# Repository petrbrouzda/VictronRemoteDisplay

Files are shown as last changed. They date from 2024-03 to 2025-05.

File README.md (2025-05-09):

# VictronRemoteDisplay
Simple remote (wifi connected) status display for Victron photovoltaic system with Cerbo GX central system without cloud access - for environments without internet connection.

Victron photovoltaic systems with Cerbo GX has display module (GX Touch 50, GX Touch 70) but they are connected to Cerbo by cable. And they are touch-enabled - you can change view, you can change system settings. 

I need wifi-connected display with **only** passive function (no configuration changes), and it run in no-internet environment (no connection to Victron VRM cloud).

So I've build this 3.5" display - as described in [VictronDisplay35](VictronDisplay35/README.md)  directory:
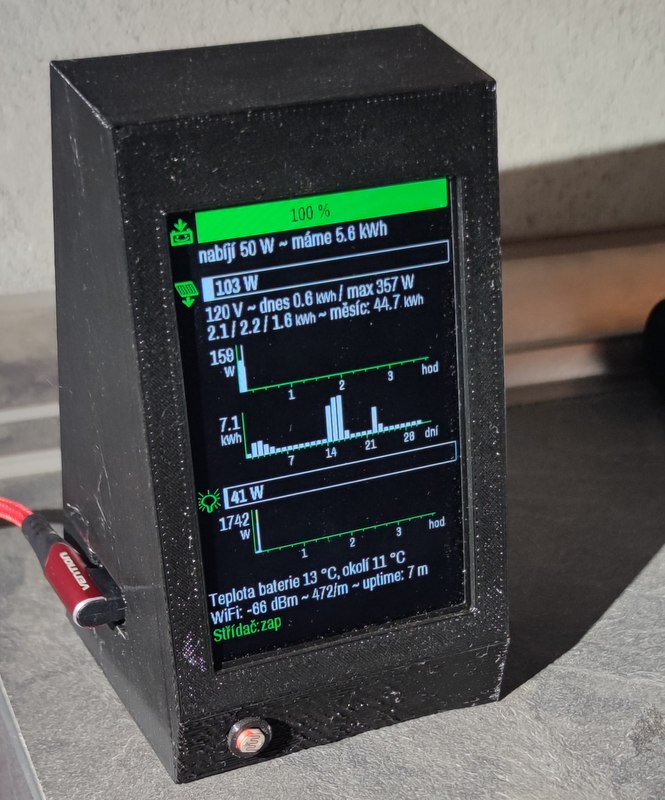
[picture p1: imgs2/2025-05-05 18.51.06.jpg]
 

Previous 1.8" display version is documented in [VictronDisplay18](VictronDisplay18/README.md)  directory:
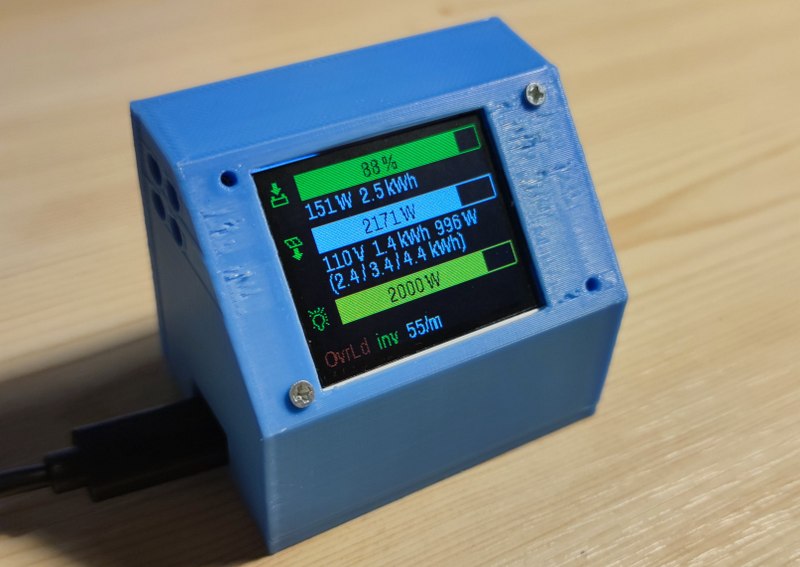
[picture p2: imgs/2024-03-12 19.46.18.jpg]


## How it works

Cerbo GX offers WiFi access point. And Cerbo GX has MQTT broker built in - you just have to switch it on in Settings. 

ESP32 can connect to Cerbo's WiFi, then connect to MQTT broker and get all information about your photovoltaic system. Seems easy.

But when you connect to Cerbo's MQTT and subscribe to all topics ("#"), you've got only one topic with ID of Cerbo's system:

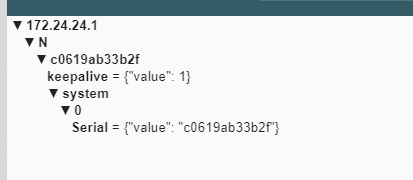
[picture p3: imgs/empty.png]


You have to read the system ID and publish **keeepalive message**: empty message to topic `R/<system ID>/keepalive` - for example `R/c0619ab33b2f/keepalive`

After you send the message, MQTT will magically starts filling with data:
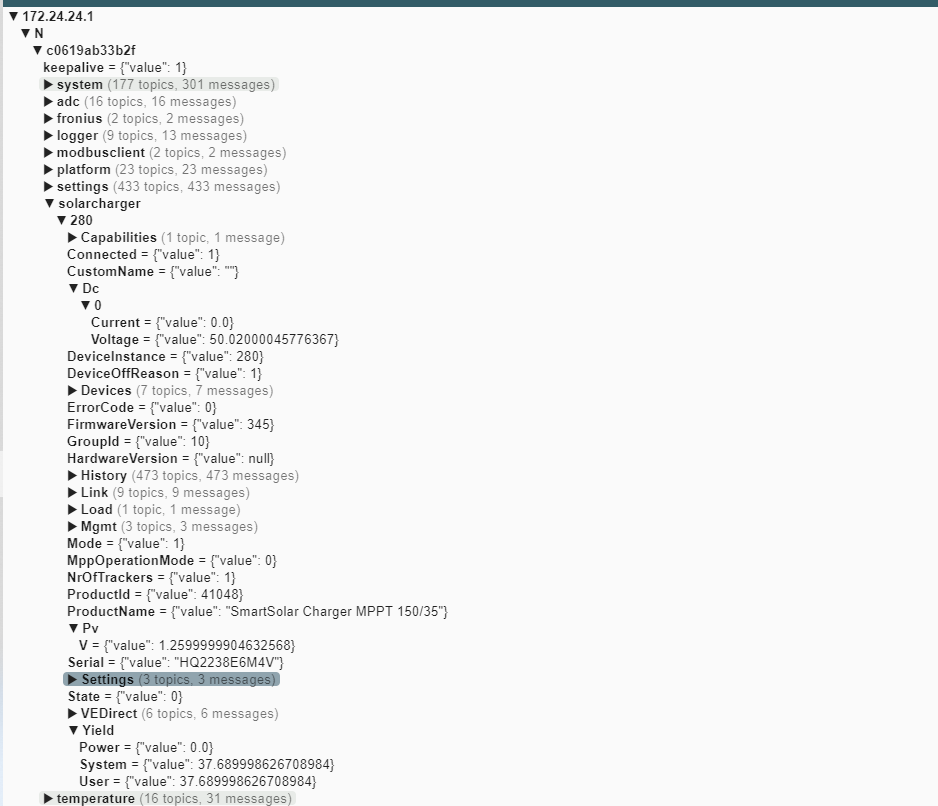
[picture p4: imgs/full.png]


But your happiness will last only for one minute, then Cerbo stops publishing more data until you send another keepalive message. So you have to send keepalive message periodically, every 55 seconds.

## Limitations

Application has been tested on three photovoltaic systems only.

It is not generic / universal tool - for example it reads data only for one battery module. If you have more batteries and they are reported as separate modules, you will have to change application. We're using two Pylontech batteries connected by data link - and they are reported as one module in Victron.

I'm using it on off-grid system, so it doesn't look for grid consumption/production. 

## Resources

https://community.victronenergy.com/questions/155407/mqtt-local-via-mqtt-broker.html

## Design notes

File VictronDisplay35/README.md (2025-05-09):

# VictronRemoteDisplay
Simple remote (wifi connected) status display for Victron photovoltaic system (with Cerbo GX central system) without cloud access - for environments without internet.

Victron photovoltaic systems with Cerbo GX has display module (GX Touch 50, GX Touch 70) but they are connected to Cerbo by cable. And they are touch-enabled - you can change view, you can change system settings. 

I need wifi-connected display with **only** passive function (no configuration changes), and it run in no-internet environment (no connection to Victron VRM cloud).

So I've build this:

 

It runs basic [ESP32-C3 board](https://s.click.aliexpress.com/e/_DEw2w8v) with [cheap 3.5" SPI display](https://s.click.aliexpress.com/e/_opxDnTV). 

Connection (display pin - ESP32 pin) is defined in config.h:
- CS - GPIO 7
- RST - GPIO 10
- DC - GPIO 6 
- SDA - GPIO 3
- SCL - GPIO 2
- BKL - GPIO 5
- VCC - 3V3
- GND - GND

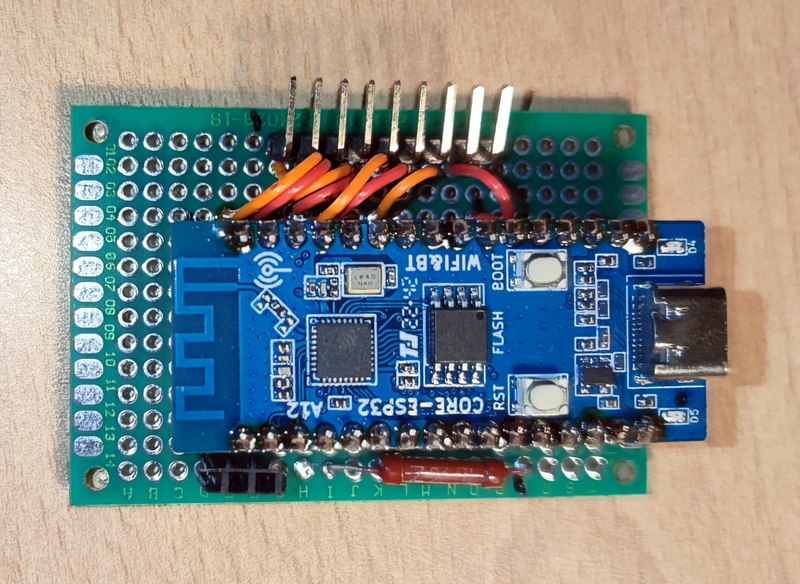
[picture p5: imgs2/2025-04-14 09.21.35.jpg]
 

There is also photoresistor for automatic backlight intensity setting. 
It is connected to GPIO 0 and used in voltage divider - so when there is much light around, voltage on GPIO 0 drops to zero; in darkness, voltage is >2.5 V.

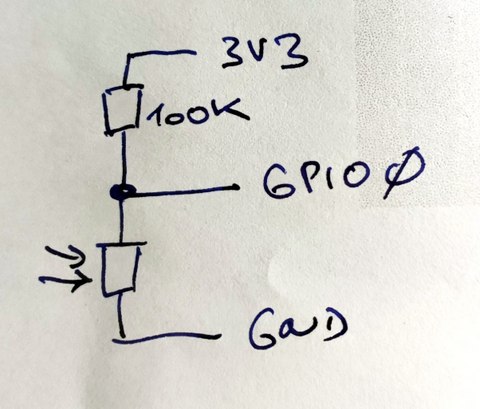
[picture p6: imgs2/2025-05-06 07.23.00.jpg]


If you haven't photoresistor, you can disable the functionality by commenting out this line in config.h:

``#define USE_BRIGHTNESS_SENSOR 
``

Box is 3D printed, STL files are in [box-display35](/box-display35/) folder.

## How it works

Cerbo GX offers WiFi access point. And Cerbo GX has MQTT broker built in - you just have to switch it on in Settings. 

ESP32 can connect to Cerbo's WiFi, then connect to MQTT broker and get all information about your photovoltaic system. Seems easy.

But when you connect to Cerbo's MQTT and subscribe to all topics ("#"), you've got only one topic with ID of Cerbo's system:



You have to read the system ID and publish **keeepalive message**: empty message to topic `R/<system ID>/keepalive` - for example `R/c0619ab33b2f/keepalive`

After you send the message, MQTT will magically starts filling with data:


But your happiness will last only for one minute, then Cerbo stops publishing more data until you send another keepalive message. So you have to send keepalive message periodically, every 55 seconds.

## How to run it

This is tested on ESP32 core for arduino version **2.0.17** (version in "board manager" in Arduino IDE). It **will not** run on current 3.0.x versions as some APIs changed in them. Switch board version to 2.0.17 before building it!

1) If your Cerbo is not connected to WiFi: switch on WiFi access point in Cerbo GX.

2) In Cerbo's console, go to **Settings - Services** and switch on **MQTT on Lan (SSL)**. Then another option will appear: **MQTT on Lan (plaintext)**. Switch it on also.

3) Edit **config.h** section with your photovoltaic system limits:

```
#define SOLAR_PANELS_POWER_WP (6.0*450.0)
#define INVERTER_POWER_W 2400.0
#define BATTERY_CAPACITY_KWH 7.0
```

4) Edit **config.h** section with connection parameters. MQTT broker address is address of Cerbo GX.

```
// WiFi
#define WIFI_SSID (const char *)"venus-XXXXXXXX-xxx"
#define WIFI_PASSWORD (const char *)"xxxxxxxx"

// MQTT Broker
#define MQTT_BROKER (const char *)"172.24.24.1"
```

5) Board configuration:
- if you have board with serial-to-USB converter: `USB-CDC on boot: disabled`
- if you have board with no serial-to-USB converter, with direct USB to ESP32-C3: `USB-CDC on boot: enabled`
- `Flash mode: DIO`
- `CPU speed: 80 MHz`
- `Flash speed: 40 MHz`

6) Used libraries (should be installed in library manager):
* PubSubClient 2.8 
* Tasker 2.0.3
* ArduinoJson 6.21.5 
* Adafruit ST7735 and ST7789 Library 1.11.0
* Adafruit GFX Library 1.12.0
* Adafruit BusIO  1.17.0
* ESP32AnalogRead 0.3.0 

7) Build application, send it into ESP and enjoy.

## What is displayed?

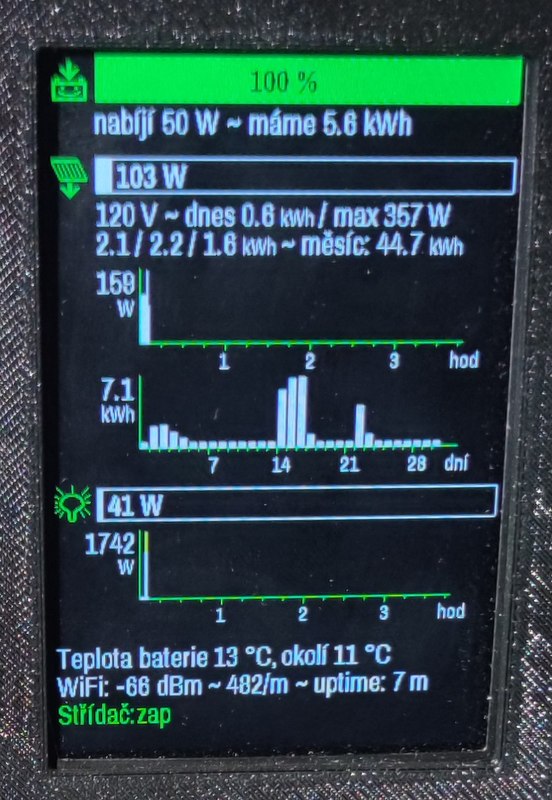
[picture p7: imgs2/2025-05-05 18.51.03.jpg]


**First bar** is **battery status.** 
* Battery icon shows if battery is charged or discharged. 
* Percentage is shown as "usable capacity". Battery will cut off at 20 %, so you've got technical reading 20 % - 100 %, which will be displayed as 0 % - 100 % here. 
* First data item (50 W) is power consumed (negative) or charging (positive). 
* Then estimated energy available (5.6 kWh); and when battery is discharged, estimated time battery will be able to suply current consumption.

Variants:

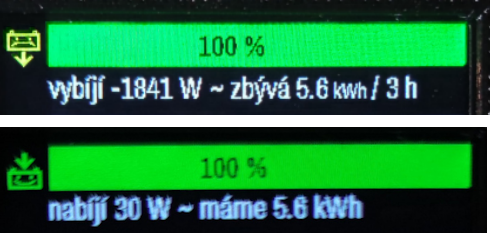
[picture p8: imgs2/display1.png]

* battery is discharging at 1841 W, estimated energy available is 5.6 kWh and it will remain for 3 hours
* battery is charging by 30 W, 5.6 kWh is available

**Second bar** is status of **solar panels**. 103 W in bar is current power supplied by panels. 
* First data row contains: 120 V = panels voltage; 0.6 kWh = today's yield; max 357 W = today maximum power supplied
* Second data row: yield yesterday / two days back / three days back; summary yield during last 31 days

Then two charts are displayed:
* panels power (W) in every minute for the last 3.5 hour
* daily yield (kWh) for last 31 days

**Third bar** is **consumption**. 41 W consumed at the moment.

It is followed by chart of consumed power in every minute for the last 3.5 hours - so you can see that the maximal consumption was 1742 W.

At the bottom three rows of status data are displayed:
* Temperature of batteries and inverter.
* WiFi strength; number of messages processed in last minute (as debug information - if connection is somewhat broken, there will be 0/m); display uptime
* Status LEDs of inverter.

## Application limitations

Application has been tested on three photovoltaic systems only.

It is not generic / universal tool - for example it reads data only for one battery module. If you have more batteries and they are reported as separate modules, you will have to change application. We're using two Pylontech batteries connected by data link - and they are reported as one module in Victron.

I'm using it on off-grid system, so it doesn't look for grid consumption/production.  

## Resources

https://community.victronenergy.com/questions/155407/mqtt-local-via-mqtt-broker.html

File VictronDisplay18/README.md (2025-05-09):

# VictronRemoteDisplay

**This is old, obsoleted version. Better version with bigger display and more information displayed is in [VictronDisplay35](../VictronDisplay35/README.md)  directory.**

Simple remote (wifi connected) status display for Victron photovoltaic system (with Cerbo GX central system) without cloud access - for environments without internet.

Victron photovoltaic systems with Cerbo GX has display module (GX Touch 50, GX Touch 70) but they are connected to Cerbo by cable. And they are touch-enabled - you can change view, you can change system settings. 

I need wifi-connected display with **only** passive function (no configuration changes), and it run in no-internet environment (no connection to Victron VRM cloud).

So I've build this:



It runs basic [ESP32-C3 board](https://s.click.aliexpress.com/e/_DEw2w8v) with [cheap 1.8" SPI display](https://s.click.aliexpress.com/e/_DeaLqWd). Without soldering - by using dupont F-F cables:
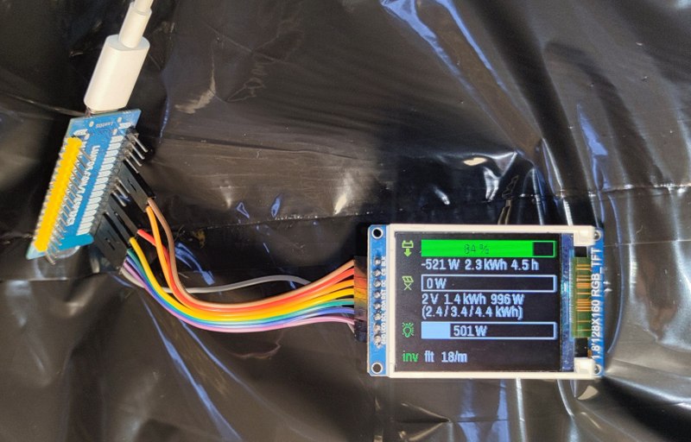
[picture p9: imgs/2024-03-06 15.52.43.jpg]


Connection (display pin - ESP32 pin):
- CS - GPIO 7
- RST - GPIO 6
- DC - GPIO 5 
- SDA - GPIO 3
- SCL - GPIO 2
- BKL - GPIO 4
- VCC - 3V3
- GND - GND

Box is 3D printed, STL files are in [box-display18](box-display18/) folder.

## How it works

Cerbo GX offers WiFi access point. And Cerbo GX has MQTT broker built in - you just have to switch it on in Settings. 

ESP32 can connect to Cerbo's WiFi, then connect to MQTT broker and get all information about your photovoltaic system. Seems easy.

But when you connect to Cerbo's MQTT and subscribe to all topics ("#"), you've got only one topic with ID of Cerbo's system:



You have to read the system ID and publish **keeepalive message**: empty message to topic `R/<system ID>/keepalive` - for example `R/c0619ab33b2f/keepalive`

After you send the message, MQTT will magically starts filling with data:


But your happiness will last only for one minute, then Cerbo stops publishing more data until you send another keepalive message. So you have to send keepalive message periodically, every 55 seconds.

## How to run it

This is tested on **2.0.x** version of ESP32 core for arduino (version in "board manager" in Arduino IDE). Probably will not run on current 3.0.x versions. Switch board version to 2.0.17 before building it!

1) If your Cerbo is not connected to WiFi: switch on WiFi access point in Cerbo GX.

2) In Cerbo's console, go to **Settings - Services** and switch on **MQTT on Lan (SSL)**. Then another option will appear: **MQTT on Lan (plaintext)**. Switch it on also.

3) Edit **config.h** section with your photovoltaic system limits:

```
#define SOLAR_PANELS_POWER_WP (6.0*450.0)
#define INVERTER_POWER_W 2400.0
#define BATTERY_CAPACITY_KWH 3.5
#define INVERTER_OWN_CONSUMPTION 20.0
```

4) Edit **config.h** section with connection parameters. MQTT broker address is address of Cerbo GX.

```
// WiFi
#define WIFI_SSID (const char *)"venus-XXXXXXXX-xxx"
#define WIFI_PASSWORD (const char *)"xxxxxxxx"

// MQTT Broker
#define MQTT_BROKER (const char *)"172.24.24.1"
```

5) Board configuration:
- if you have board with serial-to-USB converter: `USB-CDC on boot: disabled`
- if you have board with no serial-to-USB converter, with direct USB to ESP32-C3: `USB-CDC on boot: enabled`
- `Flash mode: DIO`
- `CPU speed: 80 MHz`
- `Flash speed: 40 MHz`

6) Used libraries:
* PubSubClient 2.8 
* Tasker 2.0.3
* ArduinoJson 6.21.4 
* Adafruit ST7735 and ST7789 Library 1.10.0
* Adafruit GFX Library 1.11.8
* Adafruit BusIO  1.14.4 

7) Build application, send it into ESP and enjoy.

## What is displayed?

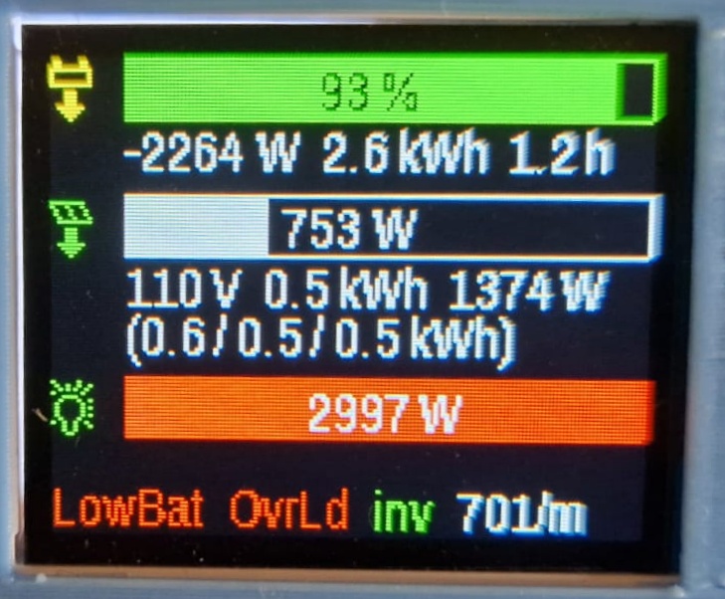
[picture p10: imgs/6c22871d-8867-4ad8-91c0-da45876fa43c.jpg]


**First bar** is **battery status.** 
* Battery icon shows if battery is charged or discharged. 
* Percentage is shown as "usable capacity". Battery will cut off at 20 %, so you've got technical reading 20 % - 100 %, which will be displayed as 0 % - 100 % here.
* First data item (-2264 W) is power consumed (negative) or charging (positive). 
* Then estimated energy available (2.6 kWh) and estimated time battery will be able to suply current consumption.

**Second bar** is status of **solar panels**. 753 W in bar is current power supplied by panels. 
* First data row contains: 110 V = panels voltage; 0.5 kWh = today's yield; 1374 W = today maximum power supplied
* Second data row: yield yesterday / two days back / three days back

**Third bar** is **consumption**. 2997 W consumed at the moment.

Last line are LEDs on inverter, so:
* Low Battery (correct - there is only one battery, which is unsupported configuration for 3 KW consumption)
* Overload (correct, inverter is rated for constant output of 2400 W)
* inv = "Inverter on"
* Last field is number of messages processed per minute (as debug information - if connection is somewhat broken, there will be 0/m).

## Application limitations

Application has been tested on only one photovoltaic system - mine. 

It is not generic / universal tool - for example it reads data only for one battery module. If you have more batteries, you will have to change application.

I'm using it on off-grid system, so it doesn't look for grid consumption/production. 

## Resources

https://community.victronenergy.com/questions/155407/mqtt-local-via-mqtt-broker.html

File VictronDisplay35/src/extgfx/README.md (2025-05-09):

Graphics objects for Adafruit_GFX and Arduino_GFX displays.

Homepage: https://github.com/petrbrouzda/ExtGfx

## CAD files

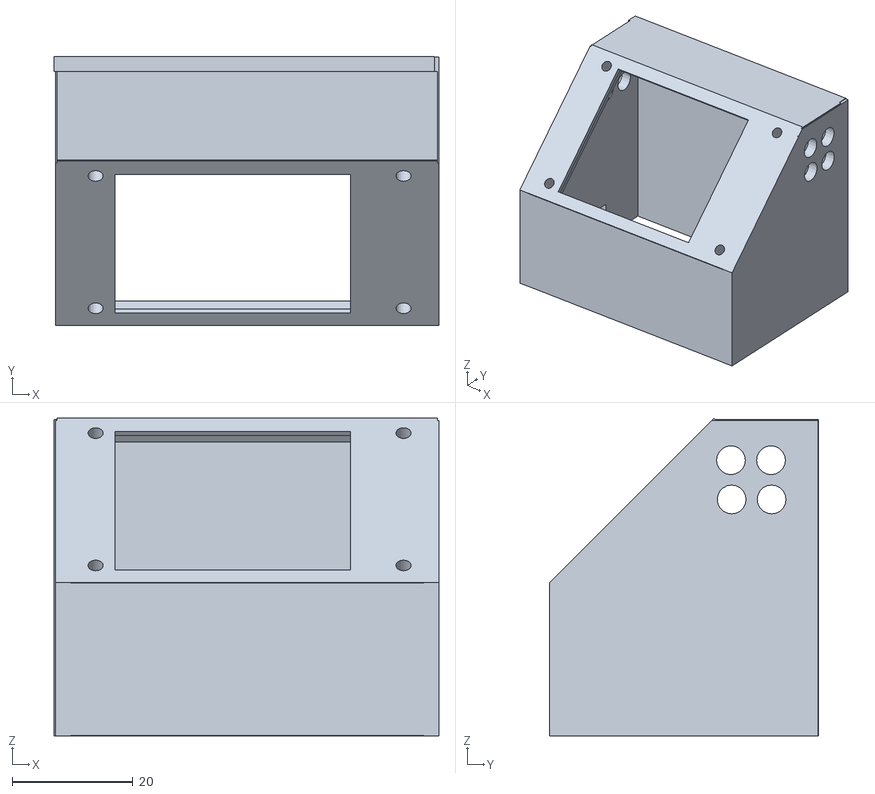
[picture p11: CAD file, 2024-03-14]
box-display18/top.stl
63.8 x 44.6 x 52.6

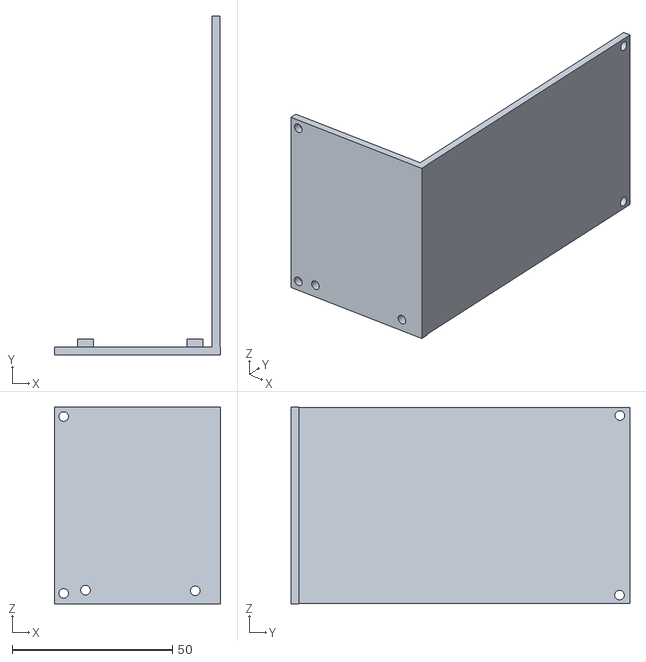
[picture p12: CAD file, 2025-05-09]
box-display35/back.stl
51.9 x 105.9 x 61.4

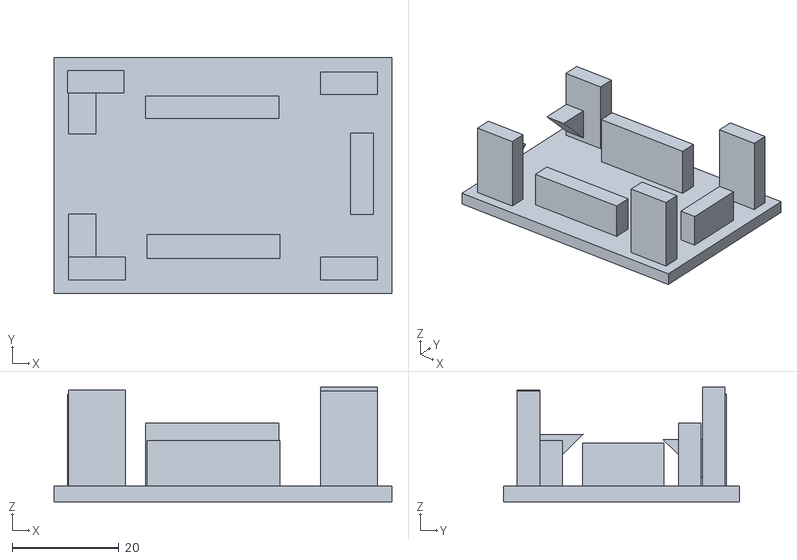
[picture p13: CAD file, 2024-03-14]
box-display18/bottom.stl
63.4 x 44.3 x 21.5

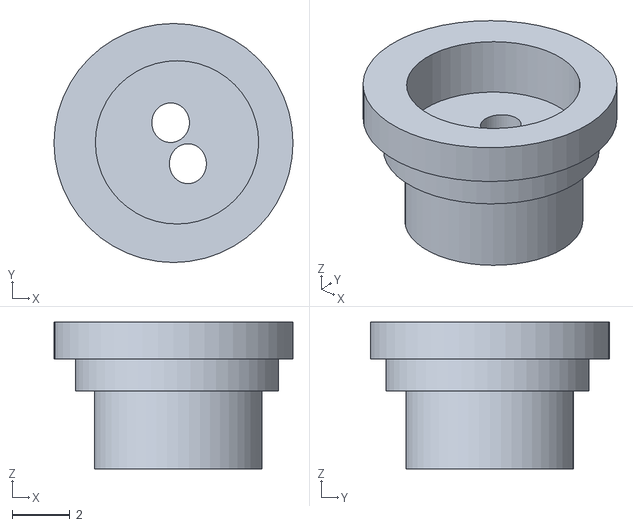
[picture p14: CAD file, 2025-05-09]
box-display35/photoresistor holder.stl
8.30 x 8.30 x 5.10

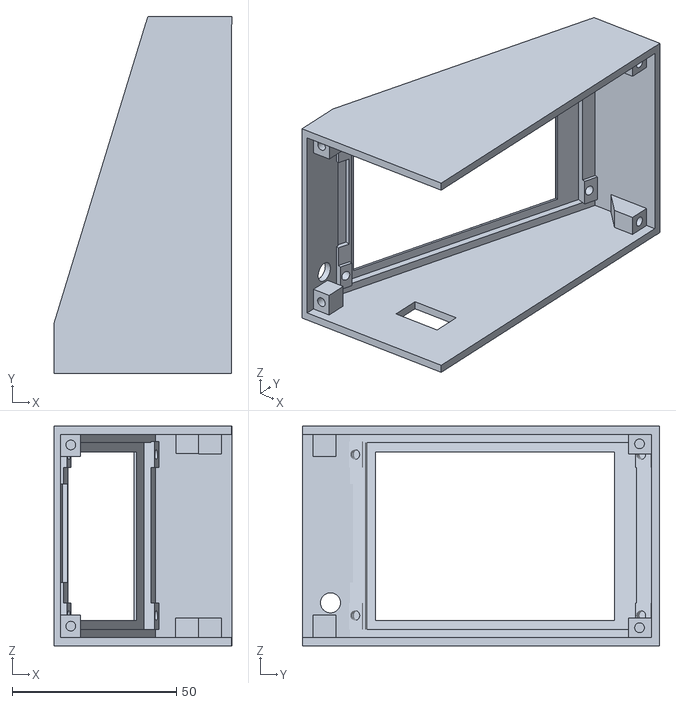
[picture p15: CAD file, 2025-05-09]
box-display35/front.stl
54.2 x 108.7 x 66.9

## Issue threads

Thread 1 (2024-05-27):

great stuff !

aktxyz, 2024-05-27:
This is fantastic, the MQTT stuff, the ESP32 approach, etc.
I am working on some tank monitoring setup using ESP32.

I have recently installed 3 victron smart chargers and can check status using the victron connect app.

What I really want is for the status on to be available on my local wifi ... have you ever played around with figuring out victron connect bluetooth and trying to get access to that info?

petrbrouzda, 2024-05-28:
I don't use bluetooth interface, because Cerbo GX contains all the information contained on bluetooth advertising.
But there are projects that do so:
- stand alone application - https://github.com/hoberman/Victron_BLE_Advertising_example
- HomeAssistant integration (this seems to be better way) - https://github.com/Fabian-Schmidt/esphome-victron_ble
-

petrbrouzda, 2024-05-28:
I don't use bluetooth interface, because Cerbo GX contains all the information contained on bluetooth advertising.
But there are projects that do so:
- stand alone application - https://github.com/hoberman/Victron_BLE_Advertising_example
- HomeAssistant integration (this seems to be better way) - https://github.com/Fabian-Schmidt/esphome-victron_ble

petrbrouzda, 2024-05-28:
I don't use bluetooth interface, because Cerbo GX contains all the information contained on bluetooth advertising.
But there are projects that do so:
- stand alone application - https://github.com/hoberman/Victron_BLE_Advertising_example
- HomeAssistant integration (this seems to be better way) - https://github.com/Fabian-Schmidt/esphome-victron_ble

Closed 2024-05-28.

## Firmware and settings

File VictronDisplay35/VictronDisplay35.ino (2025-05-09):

// FQBN: esp32:esp32:esp32c3:CDCOnBoot=cdc,FlashMode=dio

#include "config.h"

#include <WiFi.h>
#include <PubSubClient.h>

// non-interrupt task planner
// https://github.com/joysfera/arduino-tasker
#include <Tasker.h>

#include <ArduinoJson.h>
DynamicJsonDocument * json;

// pro NAN
#include <math.h>

#include "FveData.h"
FveData data;

#include "src/toolkit/DeviceInfo.h"

#include <Adafruit_GFX.h>
#include <Adafruit_ST7796S.h>

#include "fonts/PragatiNarrow-Regular16pt8b.h"
#include "fonts/PragatiNarrow-Regular20pt8b.h"
#include "fonts/PragatiNarrow-Regular22pt8b.h"
#include "fonts/PragatiNarrow-Bold22pt8b.h"
#include "fonts/icons.h"

#include "src/extgfx/TextPainter.h"
#include "src/extgfx/HorizontalBar.h"
#include "src/extgfx/SmallChart.h"
#include "src/extgfx/BasicColors.h"

#include "src/toolkit/map_double.h"

#ifdef USE_BRIGHTNESS_SENSOR
  #include <ESP32AnalogRead.h>
  ESP32AnalogRead adc;
#endif

Adafruit_ST7796S *display;
 

WiFiClient espClient;
PubSubClient mqtt(espClient);
Tasker tasker;

/** stav spojeni na MQTT */
bool mqttOK = false;

/** stav WiFi */
bool wifiOK = false;

/**
Victron device ID - needed for KeepAlive message
*/
char victronDeviceId[20];

TextPainter * painter;

TpFontConfig malePismo;
TpFontConfig vetsiPismo;
TpFontConfig velkePismo;
TpFontConfig tucnePismo;
TpFontConfig icons;

void blinkLed()
{
  pinMode( LED, OUTPUT );
  digitalWrite( LED, LOW );
  delay(500);
  digitalWrite( LED, HIGH );
  delay(500);
  digitalWrite( LED, LOW );
  delay(500);
  digitalWrite( LED, HIGH );
  delay(500);
}

/**
It is good to know what application and which version is used in device.
*/
void printStartupInfo() 
{
  Serial.printf( "%s, %s %s\n", __FILE__, __DATE__, __TIME__ );
  Serial.println( EXTGFX_VERSION );

  char tmp[200];
  formatDeviceInfo( tmp );
  Serial.println( tmp );
}

void setup() {
  
  pinMode( LED_UNUSED, OUTPUT );
  digitalWrite( LED_UNUSED, LOW );

  victronDeviceId[0] = 0;
  json = new DynamicJsonDocument(2000);
    
  Serial.begin(115200);
  blinkLed();
  printStartupInfo();

  #ifdef USE_BRIGHTNESS_SENSOR
    adc.attach(BRIGHTNESS_SENSOR_PIN);
  #endif

  // aby se objekt vytvoril vcas
  data.accuP=0;

   // ++++ zde si nastavte svuj displej

    pinMode( TFT_RST, OUTPUT );
    digitalWrite( TFT_RST, RST_VALUE );
    pinMode( TFT_BACKLIGHT, OUTPUT );
    digitalWrite( TFT_BACKLIGHT, TFT_BACKLIGHT_ON );
    
    // nastavení pro TENSTAR ROBO 3.5 Inch 320x480
    
    SPI.end(); // release standard SPI pins
    SPI.begin(TFT_SCLK, SPI_MISO_UNUSED, TFT_MOSI, TFT_CS); // map and init SPI pins
    display = new Adafruit_ST7796S(TFT_CS, TFT_DC, TFT_RST);

    display->init(320, 480, 0, 0, ST7796S_BGR );
    display->invertDisplay(true);
    display->setRotation(2);
    display->fillScreen(ST77XX_BLACK);

  // ----- nastaveni displeje

  painter = new TextPainter( display );
  painter->createFontConfig( &malePismo, &PragatiNarrow_Regular16pt8b );
  painter->createFontConfig( &vetsiPismo, &PragatiNarrow_Regular20pt8b );
  painter->createFontConfig( &velkePismo, &PragatiNarrow_Regular22pt8b );
  painter->createFontConfig( &tucnePismo, &PragatiNarrow_Bold22pt8b );
  painter->createFontConfig( &icons, &Icons );
  
  painter->setFont( &tucnePismo );
  display->setTextColor( EG_YELLOW );
  painter->printLabel( TextPainter::ALIGN_CENTER , 160, 50, (char*)"Spouštím..." );

  startWifi();

  mqtt.setServer(MQTT_BROKER, MQTT_PORT);
  mqtt.setCallback(mqqtCallback);
  // victron messages are larger than default
  mqtt.setBufferSize(1024);

  initDisplay();

  tasker.setInterval( raPrintHeap, 60000 );
  tasker.setInterval( doDisplay, 2500 );
  tasker.setInterval( minuteData, 60000 );

  #ifdef USE_BRIGHTNESS_SENSOR
    tasker.setInterval( setBrightness, 5000 );
  #endif

}

void minuteData()
{
  data.minuteCons->put( data.minuteMaxConsP );
  data.minuteProd->put( data.getSolarP() );
  data.clearMinuteMaxConsP();
}

#ifdef USE_BRIGHTNESS_SENSOR
  void setBrightness() {
    float v = adc.readVoltage();
    float svetlo = map_double( v, SENSOR_U_MIN, SENSOR_U_MAX, BL_MAX, BL_MIN );
    analogWrite( TFT_BACKLIGHT, (int)svetlo );
    Serial.printf( "adc = %.2f V -> backlight %.0f = %.0f %% \n", v, svetlo, (svetlo/2.55) );
  }
#endif

void loop() {
  checkWifiStatus();
  
  tasker.loop();

  if( wifiOK ) {
    if( !mqttOK ) {
      connectMqtt();   
    } else if( !mqtt.connected() ) {
      connectMqtt();   
    } else {
      mqtt.loop();
    }
  }


}

/**
Called periodically from Tasker
*/
void displayData() 
{
  Serial.println( data.toString() );
}


/** Time of last connect operation to MQTT. To limit maximal throughput of requests. */
long lastConnectionTry = -60000;
#define MQTT_CONN_INTERVAL_MS 10000

void connectMqtt()
{
  if (mqtt.connected()) {
    return;
  }
  mqttOK = false;

  if( millis() - lastConnectionTry < MQTT_CONN_INTERVAL_MS ) {
    return;
  }

  lastConnectionTry = millis();

  String client_id = "esp32-";
  client_id += String(WiFi.macAddress());
  Serial.printf("MQTT client %s connects to %s:%d\n", client_id.c_str(), MQTT_BROKER, MQTT_PORT );
  if (! mqtt.connect(client_id.c_str(), MQTT_USERNAME, MQTT_PASSWORD)) {
    Serial.print("MQTT failed with state ");
    Serial.println(mqtt.state());
    return;
  }

  Serial.println("MQTT Connected");
  mqttOK = true;

  if( victronDeviceId[0]==0 ) {
    // nejprve si subskribneme ID systemu, abychom vedeli, s kym si povidat
    mqtt.subscribe("N/+/system/0/Serial");
  } else {
    mqttSubscribeAll();
  }
}


/**
Subscribe only topics we can parse something from.
*/
void mqttSubscribeAll() 
{
  // mqtt.subscribe("N/#" );
  char tmp[100];
  sprintf( tmp, "N/%s/vebus/#", victronDeviceId );
  mqtt.subscribe( tmp );
  // sprintf( tmp, "N/%s/solarcharger/#", victronDeviceId );
  sprintf( tmp, "N/%s/solarcharger/+/Pv/V", victronDeviceId );
  mqtt.subscribe( tmp );
  sprintf( tmp, "N/%s/solarcharger/+/History/Daily/+/Yield", victronDeviceId );
  mqtt.subscribe( tmp );
  sprintf( tmp, "N/%s/solarcharger/+/History/Daily/0/MaxPower", victronDeviceId );
  mqtt.subscribe( tmp );
  sprintf( tmp, "N/%s/system/+/Ac/#", victronDeviceId );
  mqtt.subscribe( tmp );
  sprintf( tmp, "N/%s/system/+/Dc/#", victronDeviceId );
  mqtt.subscribe( tmp );
  sprintf( tmp, "N/%s/system/+/Batteries/#", victronDeviceId );
  mqtt.subscribe( tmp );
  sprintf( tmp, "N/%s/battery/+/Dc/0/Temperature", victronDeviceId );
  mqtt.subscribe( tmp );
  sprintf( tmp, "N/%s/temperature/+/Temperature", victronDeviceId );
  mqtt.subscribe( tmp );

  // alternative: N/%s/system/+/Dc/Pv/Power
  sprintf( tmp, "N/%s/solarcharger/+/Yield/Power", victronDeviceId );
  mqtt.subscribe( tmp );
}


/**
Called when message is received 
*/
void mqqtCallback(char *topic, byte *payload, unsigned int length) {
  data.msgs++;

  digitalWrite( LED, HIGH );

  payload[length] = 0;
  Serial.printf("> %s: %s\n", topic, payload);

  if( checkTopicName("N/+/system/0/Serial", topic ) ) {
    const char * v = getValue(payload);
    if( v!=NULL ) {
      mqtt_SystemSerialNumber( v );
    }
  } else if( checkTopicName("N/+/system/0/Dc/Battery/Power", topic ) ) {
    double v = getDoubleValue(payload);
    if( v!=NAN ) {
      data.accuP = v;
      data.update(); 
    }
  } else if( checkTopicName("N/+/system/0/Ac/Consumption/L1/Power", topic ) ) {
    double v = getDoubleValue(payload);
    if( v!=NAN ) {
      data.setConsP(v);
      data.update(); 
    }
  } else if( checkTopicName("N/+/solarcharger/+/Pv/V", topic ) ) {
    double v = getDoubleValue(payload);
    if( v!=NAN ) {
      data.solarU = v;
      data.update(); 
    }
  } else if( checkTopicName("N/+/solarcharger/+/Yield/Power", topic) ) {
    double v = getDoubleValue(payload);
    if( v!=NAN ) {
      data.solarP = v;
      data.update(); 
    }
  } else if( checkTopicName("N/+/vebus/+/Leds/Absorption", topic ) ) {
    int v = getIntValue(payload);
    if( v!=-999 ) { data.ledAbsorption = v; } 
    data.update(); 
  }  else if( checkTopicName("N/+/vebus/+/Leds/Bulk", topic ) ) {
    int v = getIntValue(payload);
    if( v!=-999 ) { data.ledBulk  = v; }
    data.update(); 
  }  else if( checkTopicName("N/+/vebus/+/Leds/Float", topic ) ) {
    int v = getIntValue(payload);
    if( v!=-999 ) { data.ledFloat  = v; }
    data.update(); 
  }  else if( checkTopicName("N/+/vebus/+/Leds/Inverter", topic ) ) {
    int v = getIntValue(payload);
    if( v!=-999 ) { data.ledInverter  = v; }
    data.update(); 
  }  else if( checkTopicName("N/+/vebus/+/Leds/LowBattery", topic ) ) {
    int v = getIntValue(payload);
    if( v!=-999 ) { data.ledLowBattery  = v; }
    data.update(); 
  }  else if( checkTopicName("N/+/vebus/+/Leds/Overload", topic ) ) {
    int v = getIntValue(payload);
    if( v!=-999 ) { data.ledOverload  = v; }
    data.update(); 
  }  else if( checkTopicName("N/+/vebus/+/Leds/Temperature", topic ) ) {
    int v = getIntValue(payload);
    if( v!=-999 ) { data.ledTemperature  = v; }
    data.update(); 
  }  else if( checkTopicName("N/+/system/0/Batteries", topic ) ) {
    /*
      Parses only _first_ battery as I have no more.
      Expected data:

      {"value": 
        [
          {
              "name": "MultiPlus-II 48/3000/35-32", 
              "soc": 92.5, 
              "power": -51, 
              "active_battery_service": true, 
              "instance": 276, 
              "id": "com.victronenergy.vebus.ttyS4", 
              "state": 2, 
              "voltage": 49.779998779296875, 
              "current": -1.600000023841858
          }
        ]
      }
    */
    DeserializationError de = deserializeJson( *json, payload );
    if( !de ) {
      if( (*json)["value"]!=NULL && (*json)["value"][0]!=NULL ) {
        double v = (*json)["value"][0]["soc"];
        if( v!=NAN) { data.accuSoc = v; }
        v = (*json)["value"][0]["voltage"];
        if( v!=NAN) { data.accuU = v; }
        v = (*json)["value"][0]["current"];
        if( v!=NAN) { data.accuI = v; }
        data.update(); 
      } 
    } else {
      Serial.printf( "JSON error: %s\n", de.c_str() );
    }
    
  } else if( checkTopicName("N/+/temperature/+/Temperature", topic ) ) {
    int v = getIntValue(payload);
    if( v!=-999 ) { data.temperatureEnv=v; } 
    data.update(); 
  } else if( checkTopicName("N/+/battery/+/Dc/0/Temperature", topic ) ) {
    int v = getIntValue(payload);
    if( v!=-999 ) { data.temperature=v; } 
    data.update(); 
  } else if( checkTopicName("N/+/solarcharger/+/History/Daily/+/Yield", topic ) ) {
    double v = getDoubleValue(payload);
    if( v!=NAN ) {
      // N/c0619ab33b2f/solarcharger/280/History/Daily/1/Yield
      #define NEEDLE "/History/Daily/"
      #define NEEDLE_LEN 15
      char * p = strstr( topic, NEEDLE );
      int dayNr = atoi( p+NEEDLE_LEN );
      data.dailyYield->setItem( dayNr, v );
      // Serial.printf( "  dailyYield[%d] = %.1f\n", dayNr, v );
    }
  } else if( checkTopicName("N/+/solarcharger/+/History/Daily/0/MaxPower", topic ) ) {
    double v = getDoubleValue(payload);
    if( v!=NAN ) {
      data.day0solarMaxPower = v;
    }
  }

  digitalWrite( LED, LOW );
}

/**
Called when Victron system ID is received
*/
void mqtt_SystemSerialNumber( const char * sernum ) 
{
  if( victronDeviceId[0]==0 ) {
    Serial.printf( "System serial ID: %s\n", sernum );
    strcpy( victronDeviceId, sernum );
    mqttSubscribeAll();
    sendKeepAlive();
    tasker.setInterval( sendKeepAlive, 55000 );
    tasker.setInterval( displayData, 60000 );
  }
}


/**
Gets value from basic message:
  {"value": "c0619ab33b2f"}
*/
const char * getValue(unsigned char * payload) {
  DeserializationError de = deserializeJson( *json, payload );
  if( !de ) {
    const char * text1 = (*json)["value"];
    return text1;
  } else {
    Serial.printf( "JSON error: %s\n", de.c_str() );
    return NULL;
  }
}

/**
Gets value from basic message:
  {"value": 11.2 }
*/
double getDoubleValue(unsigned char * payload ) {
  DeserializationError de = deserializeJson( *json, payload );
  if( !de ) {
    double v = (*json)["value"];
    return v;
  } else {
    Serial.printf( "JSON error: %s\n", de.c_str() );
    return NAN;
  }
}


/**
Gets value from basic message:
  {"value": 1}
*/
int getIntValue(unsigned char * payload) {
  DeserializationError de = deserializeJson( *json, payload );
  if( !de ) {
    int v = (*json)["value"];
    return v;
  } else {
    Serial.printf( "JSON error: %s\n", de.c_str() );
    return -999;
  }
}


/**
Checks if topic name equals to a mask.
Mask can contain '+' as folder name wildcard

  "N/+/system/0/Serial" == "N/c0619ab33b2f/system/0/Serial"
*/ 
bool checkTopicName( const char * mask, char * topic ) {
  int mask_i = 0;
  int topic_i = 0;
  while( true ) {
    if( mask[mask_i]==0 && topic[topic_i]==0 ) {
      return true;
    }
    if( mask[mask_i]==0 || topic[topic_i]==0 ) {
      return false;
    }
    if( mask[mask_i]=='+' ) {
      mask_i++;
      // rolovat topic az do /
      while(topic[topic_i]!='/' && topic[topic_i]!=0) {
        topic_i++;
      }
    }
    if( mask[mask_i] != topic[topic_i] ) {
      return false;
    }
    mask_i++;
    topic_i++;
  }
}

/* ******************* Keep alive  *********************/

/**
Must send keep alive request every 55 sec to get any data
Called from tasker.
Tasker set up from mqtt_SystemSerialNumber().
https://community.victronenergy.com/questions/155407/mqtt-local-via-mqtt-broker.html
*/
void sendKeepAlive()
{
  if( mqttOK && mqtt.connected() ) {
    char topic[50];
    sprintf( topic, "R/%s/keepalive", victronDeviceId );
    mqtt.publish( topic, "");
    Serial.println( "* KA" );
  }
}




/*  ******************** Memory info *******************************************  */

int prevFreeHeap = ESP.getFreeHeap();

/**
 * Vola se jednou za minutu a vypise stav heapu
 */
void raPrintHeap()
{
    long freeHeap = ESP.getFreeHeap();
    long delta = freeHeap-prevFreeHeap;
    prevFreeHeap = freeHeap;
    Serial.printf( "~ heap: %d, delta %d; PSRAM: %d\n", freeHeap, delta, ESP.getFreePsram() );
}


/*  ******************** WiFi callbacks *******************************************  */


void wifiStatus_Connected(  int status, int waitTime, IPAddress ip, int rssi  )
{
  Serial.print("* wifi [");
  Serial.print( ip );
  Serial.printf("], %d dBm, %d s\n", rssi, waitTime );

  connectMqtt();
}

void wifiStatus_NotConnected( int status, long msecNoConnTime )
{
  Serial.printf("* no wifi (%s), %d s\n", getWifiStatusText(status), (msecNoConnTime / 1000L) );
  
  if( mqttOK ) {
    mqttOK = false;
    mqtt.disconnect();
  }
}

void wifiStatus_Starting()
{ 
}


/* ************************** vypis pouzitych knihoven **************************** */

/*
Using library WiFi at version 2.0.0 in folder: C:\Users\brouzda\AppData\Local\Arduino15\packages\esp32\hardware\esp32\2.0.17\libraries\WiFi 
Using library PubSubClient at version 2.8 in folder: E:\dev.moje\arduino\libraries\PubSubClient 
Using library Tasker at version 2.0.3 in folder: E:\dev.moje\arduino\libraries\Tasker 
Using library ArduinoJson at version 6.21.5 in folder: E:\dev.moje\arduino\libraries\ArduinoJson 
Using library Adafruit GFX Library at version 1.12.0 in folder: E:\dev.moje\arduino\libraries\Adafruit_GFX_Library 
Using library Adafruit BusIO at version 1.17.0 in folder: E:\dev.moje\arduino\libraries\Adafruit_BusIO 
Using library Wire at version 2.0.0 in folder: C:\Users\brouzda\AppData\Local\Arduino15\packages\esp32\hardware\esp32\2.0.17\libraries\Wire 
Using library SPI at version 2.0.0 in folder: C:\Users\brouzda\AppData\Local\Arduino15\packages\esp32\hardware\esp32\2.0.17\libraries\SPI 
Using library Adafruit ST7735 and ST7789 Library at version 1.11.0 in folder: E:\dev.moje\arduino\libraries\Adafruit_ST7735_and_ST7789_Library 
Using library ESP32AnalogRead at version 0.3.0 in folder: E:\dev.moje\arduino\libraries\ESP32AnalogRead 
*/

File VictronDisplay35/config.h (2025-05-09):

#ifndef __MY_CONFIG_H_
#define __MY_CONFIG_H_

/****************** FV system parameters ***************/

#define SOLAR_PANELS_POWER_WP (6.0*450.0)
#define INVERTER_POWER_W 2400.0
#define BATTERY_CAPACITY_KWH 7.0

// if battery gets hotter than that, red text will be displayed
#define BATTERY_TEMP_LIMIT 28


/****************** hardware configuration ***************/


// WiFi restart interval if there is no connection
#define WIFI_NOCONN_RESTART_SEC 30

// parametry pripojeni displeje
#define TFT_CS   7
#define TFT_RST  10
#define TFT_DC   6
#define TFT_MOSI 3
#define TFT_SCLK 2

#define SPI_MISO_UNUSED -1

// nastavení RST do režimu ne-reset
#define RST_VALUE HIGH 

// LOW = vypnuto, HIGH = zapnuto
#define TFT_BACKLIGHT 5

#define LED 12
#define LED_UNUSED 13

#define TFT_BACKLIGHT_ON HIGH

// comment out if you have no solar-resistor in circuit
#define USE_BRIGHTNESS_SENSOR 

#ifdef USE_BRIGHTNESS_SENSOR 
    #define BRIGHTNESS_SENSOR_PIN 0

    #define SENSOR_U_MIN 0.6
    #define SENSOR_U_MAX 2.0

    #define BL_MAX 255.0
    #define BL_MIN 10.0
#endif


/****************** connection parameters ***************/



// WiFi
#define WIFI_SSID (const char *)"venus-XXXXX-xxx"
#define WIFI_PASSWORD (const char *)"xxxxxxxxx"

// MQTT Broker
#define MQTT_BROKER (const char *)"172.24.24.1"
#define MQTT_USERNAME (const char *)""
#define MQTT_PASSWORD (const char *)""
#define MQTT_PORT 1883




#endif

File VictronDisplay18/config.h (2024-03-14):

#ifndef __MY_CONFIG_H_
#define __MY_CONFIG_H_

/****************** FV system parameters ***************/

#define SOLAR_PANELS_POWER_WP (6.0*450.0)
#define INVERTER_POWER_W 2400.0
#define BATTERY_CAPACITY_KWH 3.5
#define INVERTER_OWN_CONSUMPTION 20.0


/****************** hardware configuration ***************/

// LED indicator
#define LED 12

// WiFi restart interval if there is no connection
#define WIFI_NOCONN_RESTART_SEC 600

// working set of pins on ESP32-C3 https://wiki.luatos.com/chips/esp32c3/board.html
#define TFT_CS        7
#define TFT_RST        6
#define TFT_DC        5 
#define TFT_MOSI 3
#define TFT_SCLK 2

#define SPI_MISO_UNUSED 10

// LOW = backlight off
#define TFT_BACKLIGHT 4


/****************** connection parameters ***************/


// WiFi
#define WIFI_SSID (const char *)"venus-XXXXXXXX-xxx"
#define WIFI_PASSWORD (const char *)"xxxxxxxx"

// MQTT Broker
#define MQTT_BROKER (const char *)"172.24.24.1"
#define MQTT_USERNAME (const char *)""
#define MQTT_PASSWORD (const char *)""
#define MQTT_PORT 1883


#endif

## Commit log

2024-03-14 initial import
    [bottom.stl, top.stl]
2025-05-09 new 3.5" display version
    [back.stl, front.stl, photoresistor holder.stl]
2025-05-09 ESP32 core version requirement
